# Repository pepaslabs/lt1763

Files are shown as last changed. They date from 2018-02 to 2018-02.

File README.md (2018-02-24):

# lt1763

A low-noise supply based on the [LT1763](http://cds.linear.com/docs/en/datasheet/1763fh.pdf).

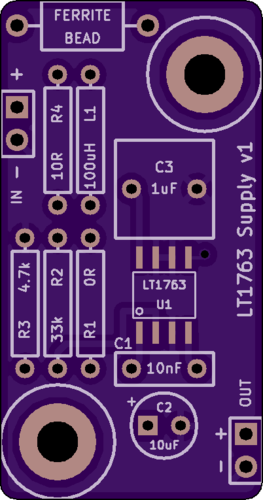
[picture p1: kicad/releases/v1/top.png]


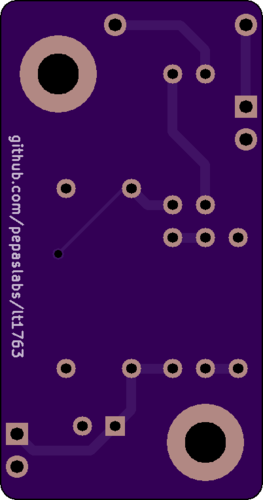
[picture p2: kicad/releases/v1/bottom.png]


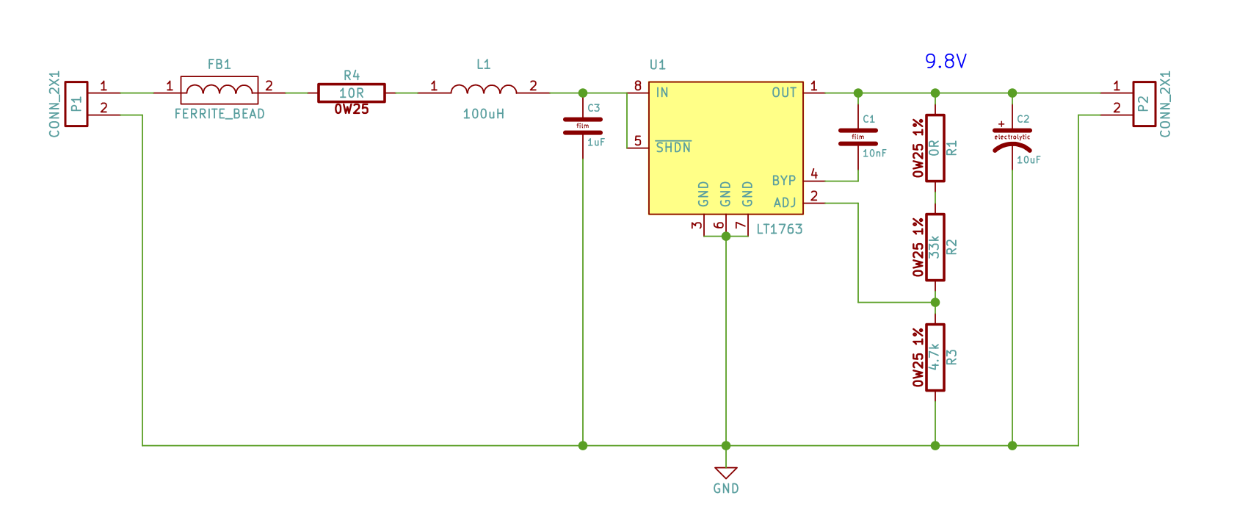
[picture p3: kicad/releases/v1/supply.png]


Schematic: [pdf](kicad/releases/v1/supply.pdf)

OSHPark: [link](https://oshpark.com/shared_projects/uVr4yDgz)

Gerbers: [zip](kicad/releases/v1/gerbers.zip)

# Input filter

The board has provisions for an RLC input filter (see schematic components R4, L1, C3).



You can populate these components with whatever values you like.  I used [this RLC calculator](http://sim.okawa-denshi.jp/en/RLCtool.php) to analyze a few component values.

Note: C3 should be a film capacitor, e.g. Kemet R82 ([4.7uF](https://www.digikey.com/product-detail/en/kemet/R82CC4470AA30J/399-6028-ND/2704682), [1uF](https://www.digikey.com/product-detail/en/kemet/R82DC4100AA60J/399-5860-ND/2571295)).

Note: L1 should be a small-signal axial inductor ([470uH](https://www.digikey.com/product-detail/en/bourns-inc/78F471J-RC/M10142-ND/1306000), [100uH](https://www.digikey.com/product-detail/en/bourns-inc/78F101J-RC/M10136-ND/1305994)).  Note that the 470uH inductor will saturate if more than 90mA is passed.  This board is intended for use with e.g. an LTZ1000 circuit, which only draws about 30mA.

Note: A 10R resistor passing 30mA will add 0.3V of dropout.

## 10R, 100uH, 1uF

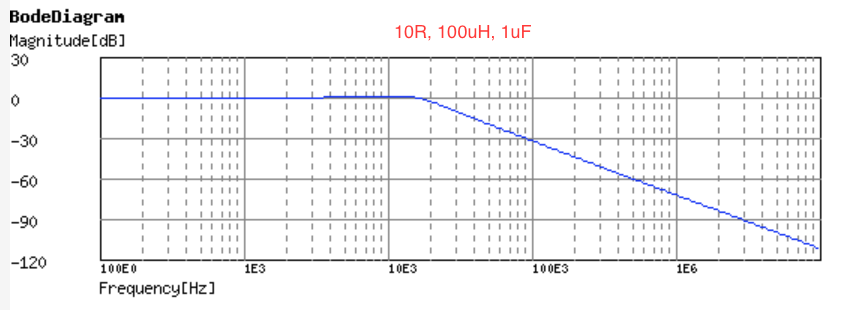
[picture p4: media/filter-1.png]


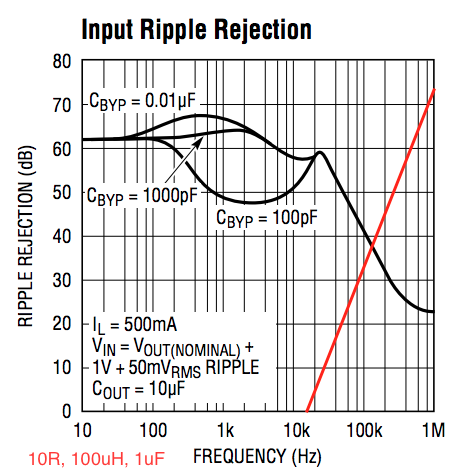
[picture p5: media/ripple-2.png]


## 10R, 470uH, 4.7uF

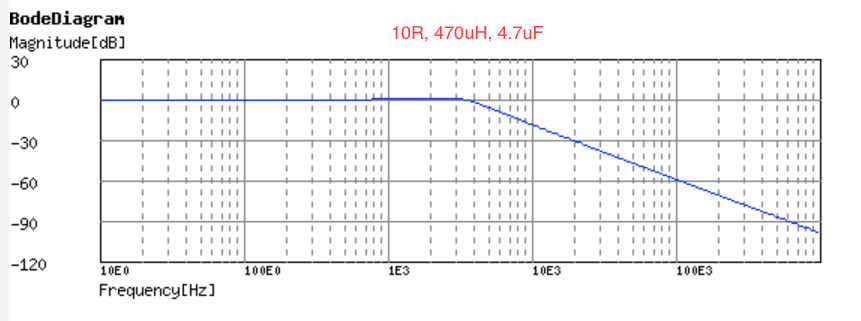
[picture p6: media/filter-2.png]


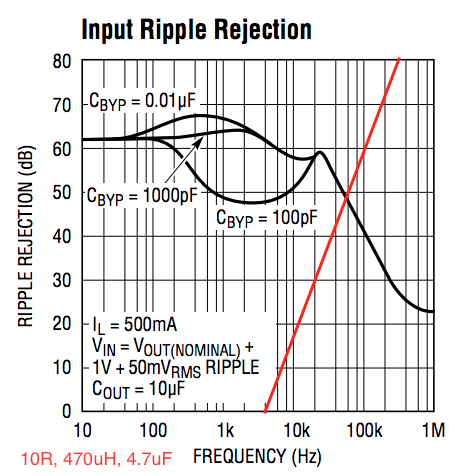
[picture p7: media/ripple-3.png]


# Mounting holes

The mounting holes are intended for use with M3 brass hex stand-offs.

# Lead spacing

The input and output leads fall on a 0.1" grid (breadboard compatible).

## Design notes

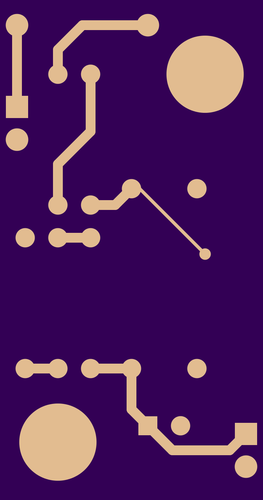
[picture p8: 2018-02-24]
kicad/releases/v1/bottom-copper.png

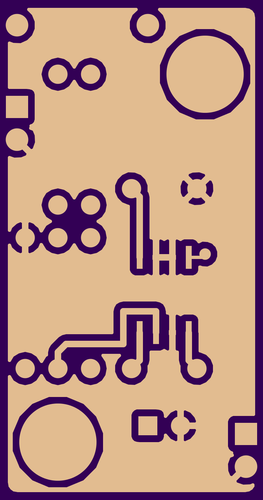
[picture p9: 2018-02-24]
kicad/releases/v1/top-copper.png

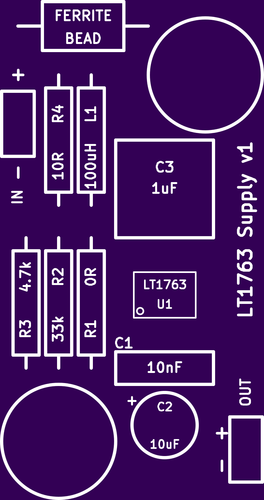
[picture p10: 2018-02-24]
kicad/releases/v1/top-silk.png

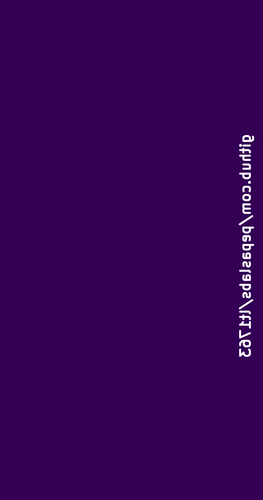
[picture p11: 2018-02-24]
kicad/releases/v1/bottom-silk.png

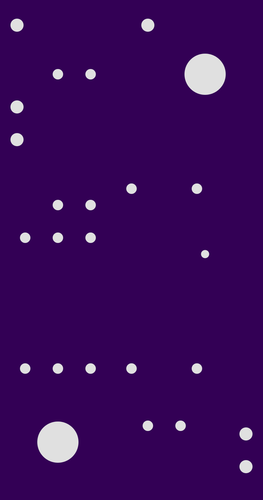
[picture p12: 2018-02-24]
kicad/releases/v1/drills.png

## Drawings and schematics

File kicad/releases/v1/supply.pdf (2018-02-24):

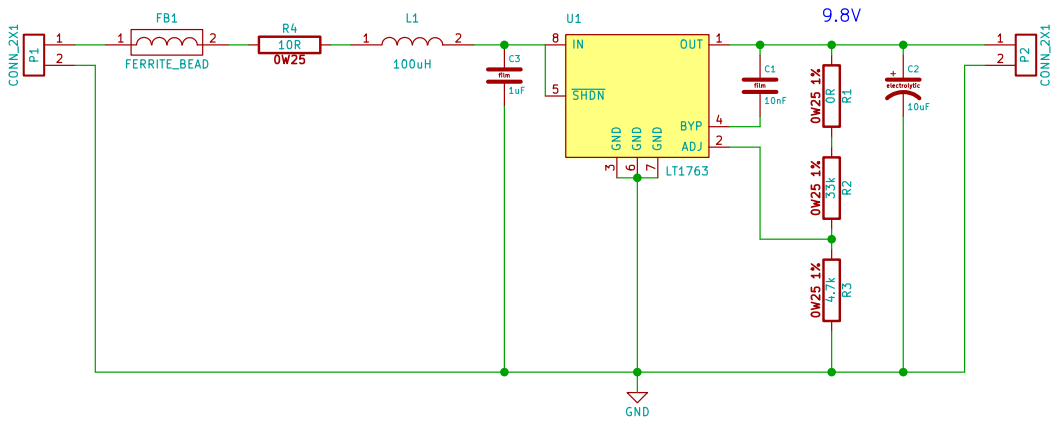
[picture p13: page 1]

Id: 1/1 Title: File: supply.sch
Sheet: /

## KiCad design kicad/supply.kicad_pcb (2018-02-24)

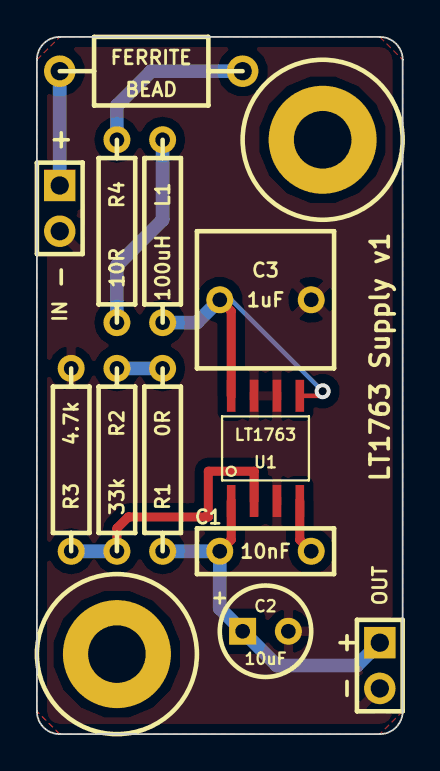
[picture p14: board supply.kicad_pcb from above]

Board: 2 copper layers, 20.3 x 38.7 mm, 14 parts (0 on the bottom side), 9 nets.

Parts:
C1: 10nF; BOXCAP_01_03_02_059A
C2: 10uF; ELCAP_10_20_V_059A
C3: 1uF; BOXCAP_02_03_03_059A
FERRITE: BEAD; FERRITE_AXIAL_04_069A
H***: Val**; hole_M3
H***#2: Val**; hole_M3
L1: 100uH; R_AXIAL_0W25_059A_PL
P1, P2: CONN_2X1; SIL-2
R1: 0R; R_AXIAL_0W25_059A_PL
R2: 33k; R_AXIAL_0W25_059A_PL
R3: 4.7k; R_AXIAL_0W25_059A_PL
R4: 10R; R_AXIAL_0W25_059A_PL
U1: LT1763; SO-8

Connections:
GND: C2.2, C3.2, P1.2, P2.2, R3.2, U1.3, U1.6, U1.7
unnamed: C1.1, C2.1, P2.1, R1.1, U1.1
unnamed: C1.2, U1.4
unnamed: R2.2, R3.1, U1.2
unnamed: R1.2, R2.1
unnamed: L1.1, R4.2
unnamed: FERRITE.1, P1.1
unnamed: C3.1, L1.2, U1.5, U1.8
unnamed: FERRITE.2, R4.1

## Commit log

2018-02-24 initial release
    [supply-B_Cu.gbl, supply-B_Mask.gbs, supply-B_SilkS.gbo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]
2018-02-24 board shots, readme
